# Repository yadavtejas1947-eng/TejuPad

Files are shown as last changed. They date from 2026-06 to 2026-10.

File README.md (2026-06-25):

# TejuPad
This is a 3*3 macropad built to increase your productivity by providing shortcut button for your most important tasks like pushing code , opening some app or website , controlling your music volume etc.  This Macropad is built on QMK firmware and matrix circuit using KiCad for the schematics and Fusion for the enclosure design.

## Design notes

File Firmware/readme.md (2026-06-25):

# teju_pad

`teju_pad` is a custom 3x3 QMK macropad powered by an RP2040 controller. It includes a rotary encoder, OLED display support, media keys, function keys, and per-key RGB matrix lighting using 9 WS2812/SK6812-style LEDs.

## Features

- 3x3 key matrix
- RP2040 MCU support
- Rotary encoder
- 128x64 OLED display over I2C
- RGB matrix lighting with 9 LEDs
- Media keys using QMK ExtraKey
- Bootmagic Lite support
- Dedicated RGB control layer
- Dedicated function-key layer

## Hardware

- **Keyboard Maintainer:** TejasYadav
- **MCU:** RP2040
- **Board:** `GENERIC_RP_RP2040`
- **Bootloader:** `rp2040`
- **Matrix:** 3 rows x 3 columns
- **Diode Direction:** `COL2ROW`
- **OLED:** 128x64 I2C display
- **RGB:** 9 WS2812/SK6812-style addressable LEDs

## Pinout

| Function | Pins |
| --- | --- |
| Rows | `GP3`, `GP0`, `GP7` |
| Columns | `GP27`, `GP6`, `GP29` |
| Encoder A/B | `GP2`, `GP1` |
| OLED SCL | `GP28` |
| OLED SDA | `GP4` |
| RGB Data | `GP26` |

## Default Layout

```text
Base layer
+---------+---------+---------+
|  Mute   | Vol -   | Vol +   |
+---------+---------+---------+
| KP 7    | KP 8    | KP 9    |
+---------+---------+---------+
| RGB     | KP 0    | FN      |
+---------+---------+---------+
```

```text
FN layer
+---------+---------+---------+
| F10     | F11     | F12     |
+---------+---------+---------+
| F7      | F8      | F9      |
+---------+---------+---------+
| F4      | F5      | Trans   |
+---------+---------+---------+
```

```text
RGB layer
+---------+---------+---------+
| Toggle  | Hue +   | Hue -   |
+---------+---------+---------+
| Sat +   | Sat -   | Val +   |
+---------+---------+---------+
| Trans   | Val -   | Boot    |
+---------+---------+---------+
```

## Encoder Behavior

| Active Layer | Counter-clockwise | Clockwise |
| --- | --- | --- |
| Base | Volume down | Volume up |
| FN | Page down | Page up |
| RGB | RGB brightness down | RGB brightness up |

## Building

From the QMK firmware root directory, build the default keymap with:

```sh
make teju_pad:default
```

## Flashing

Put the board into bootloader mode, then run:

```sh
make teju_pad:default:flash
```

## Bootloader

You can enter the bootloader in any of these ways:

- Hold the top-left key while plugging in the keyboard.
- Press the physical reset/boot button on the controller or PCB.
- Use the `QK_BOOT` key on the RGB layer.

## Disclaimer

This firmware was created with AI assistance:

- **Firmware:** Claude
- **README.md:** Codex

Please review, test, and verify the firmware on your own hardware before relying on it for daily use.

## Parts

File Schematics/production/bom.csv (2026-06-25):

Designator | Footprint | Quantity | Value | LCSC Part #
D1, D10, D2, D3, D4, D5, D6, D7, D8, D9 | D_DO-35_SOD27_P7.62mm_Horizontal | 10 | 1N4148
D11, D12, D13, D14, D15, D16, D17, D18, D19 | LED_SK6812MINI_PLCC4_3.5x3.5mm_P1.75mm | 9 | SK6812MINI
SW1, SW2, SW3, SW4, SW5, SW6, SW7, SW8, SW9 | SW_Cherry_MX_1.00u_PCB | 9 | SW_Push
SW10 | RotaryEncoder_Alps_EC11E-Switch_Vertical_H20mm | 1 | RotaryEncoder_Switch
U1 | ER_OLEDM0.91_1x-I2C | 1 | ER_OLEDM0.91_1x-I2C
U2 | XIAO-RP2040-DIP | 1 | XIAO-RP2040-DIP

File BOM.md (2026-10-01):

# TJ Pad — bill of materials

<!-- Generated by Half Life from project cmupau83t04sp01s1058a6cvx. Edits here are overwritten on the next sync. -->
<!-- Generated: 1970-01-01T00:00:00.000Z -->

> [!NOTE]
> This parts list is mirrored from [Half Life](https://halflife.hackclub.com). Editing it here will not change the platform's copy, and the next sync overwrites this file.

| Week | Tier | Parts funding |
| --- | --- | --- |
| Warm-up | Tier 1 | $30.00 |

_No parts listed yet._

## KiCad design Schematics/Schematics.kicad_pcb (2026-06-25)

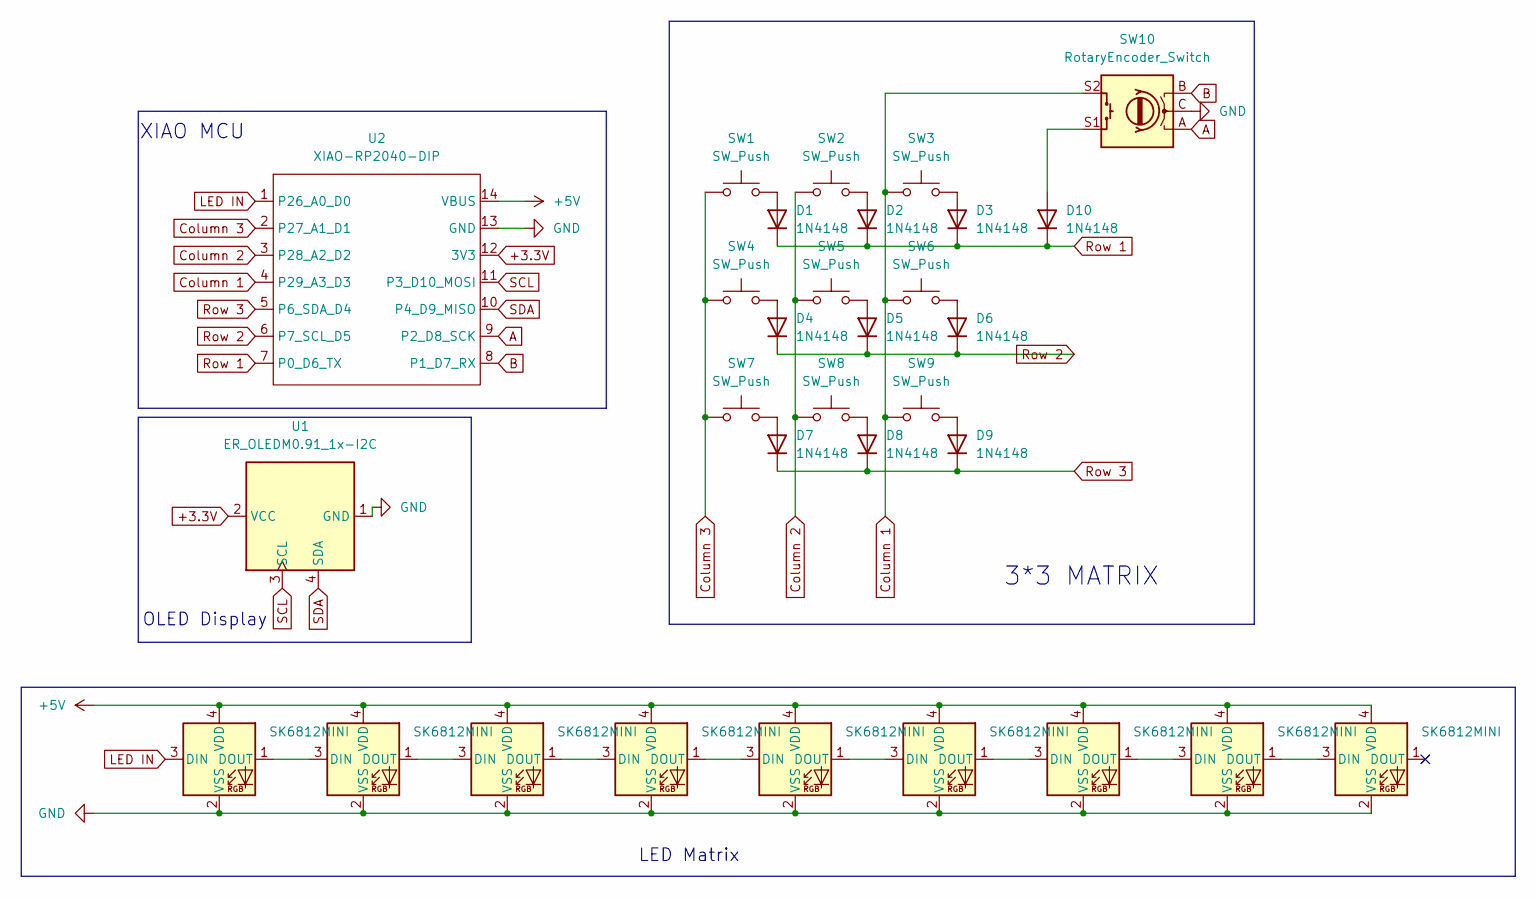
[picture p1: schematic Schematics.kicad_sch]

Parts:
D1, D2, D3, D4, D5, D6, D7, D8, D9, D10: 1N4148; D_DO-35_SOD27_P7.62mm_Horizontal
D11, D12, D13, D14, D15, D16, D17, D18, D19: SK6812MINI; LED_SK6812MINI_PLCC4_3.5x3.5mm_P1.75mm
SW1, SW2, SW3, SW4, SW5, SW6, SW7, SW8, SW9: SW_Push; SW_Cherry_MX_1.00u_PCB
SW10: RotaryEncoder_Switch; RotaryEncoder_Alps_EC11E-Switch_Vertical_H20mm
U1: ER_OLEDM0.91_1x-I2C
U2: XIAO-RP2040-DIP

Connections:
+3.3V: U1.2 (VCC), U2.12 (3V3)
+5V: D11.4 (VDD), D12.4 (VDD), D13.4 (VDD), D14.4 (VDD), D15.4 (VDD), D16.4 (VDD), D17.4 (VDD), D18.4 (VDD), D19.4 (VDD), U2.14 (VBUS)
A: SW10.A, U2.9 (P2_D8_SCK)
B: SW10.B, U2.8 (P1_D7_RX)
Column 1: SW3.1, SW6.1, SW9.1, SW10.S2, U2.4 (P29_A3_D3)
Column 2: SW2.1, SW5.1, SW8.1, U2.3 (P28_A2_D2)
Column 3: SW1.1, SW4.1, SW7.1, U2.2 (P27_A1_D1)
GND: D11.2 (VSS), D12.2 (VSS), D13.2 (VSS), D14.2 (VSS), D15.2 (VSS), D16.2 (VSS), D17.2 (VSS), D18.2 (VSS), D19.2 (VSS), SW10.C, U1.1 (GND), U2.13 (GND)
LED IN: D11.3 (DIN), U2.1 (P26_A0_D0)
unnamed: D1.2 (A), SW1.2
unnamed: D2.2 (A), SW2.2
unnamed: D3.2 (A), SW3.2
unnamed: D4.2 (A), SW4.2
unnamed: D5.2 (A), SW5.2
unnamed: D6.2 (A), SW6.2
unnamed: D7.2 (A), SW7.2
unnamed: D8.2 (A), SW8.2
unnamed: D9.2 (A), SW9.2
unnamed: D10.2 (A), SW10.S1
unnamed: D11.1 (DOUT), D12.3 (DIN)
unnamed: D12.1 (DOUT), D13.3 (DIN)
unnamed: D13.1 (DOUT), D14.3 (DIN)
unnamed: D14.1 (DOUT), D15.3 (DIN)
unnamed: D15.1 (DOUT), D16.3 (DIN)
unnamed: D16.1 (DOUT), D17.3 (DIN)
unnamed: D17.1 (DOUT), D18.3 (DIN)
unnamed: D18.1 (DOUT), D19.3 (DIN)
Row 1: D1.1 (K), D2.1 (K), D3.1 (K), D10.1 (K), U2.7 (P0_D6_TX)
Row 2: D4.1 (K), D5.1 (K), D6.1 (K), U2.6 (P7_SCL_D5)
Row 3: D7.1 (K), D8.1 (K), D9.1 (K), U2.5 (P6_SDA_D4)
SCL: U1.3 (SCL), U2.11 (P3_D10_MOSI)
SDA: U1.4 (SDA), U2.10 (P4_D9_MISO)

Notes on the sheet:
3*3 MATRIX
XIAO MCU
LED Matrix
OLED Display

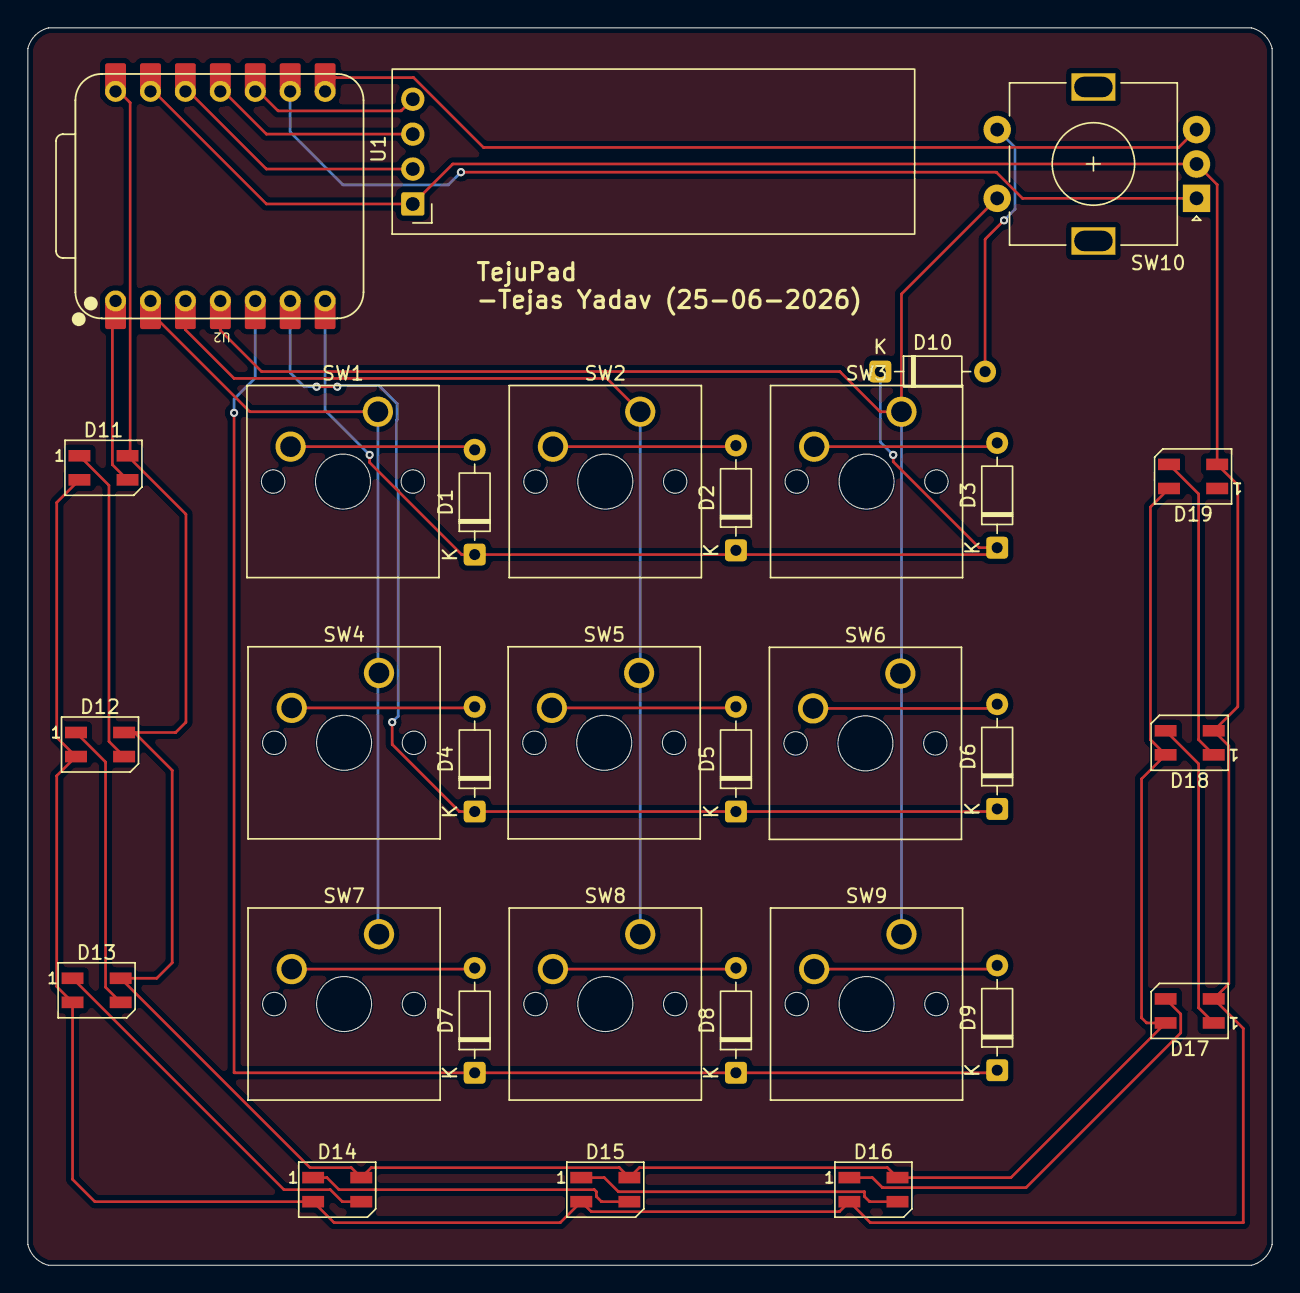
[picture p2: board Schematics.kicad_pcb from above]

Board: 2 copper layers, 90.5 x 90.0 mm, 31 parts (0 on the bottom side), 32 nets.

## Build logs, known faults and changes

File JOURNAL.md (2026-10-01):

# TJ Pad — devlog

<!-- Generated by Half Life from project cmupau83t04sp01s1058a6cvx. Edits here are overwritten on the next sync. -->
<!-- Generated: 1970-01-01T00:00:00.000Z -->

> [!NOTE]
> This devlog is mirrored from [Half Life](https://halflife.hackclub.com). Editing it here will not change the platform's copy, and the next sync overwrites this file.

> This is a 3*3 Macropad

| Week | Tier | Hours logged | Entries |
| --- | --- | --- | --- |
| Warm-up | Tier 1 | 0h | 0 |

_No entries logged yet._

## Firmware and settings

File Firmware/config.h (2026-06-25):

#pragma once

/* I2C for OLED — D2=GP28 (SCL), D9=GP4 (SDA) */
#define I2C_DRIVER        I2CD1
#define I2C1_SCL_PIN      GP28
#define I2C1_SDA_PIN      GP4

/* OLED */
#define OLED_DISPLAY_128X64
#define OLED_TIMEOUT      30000   /* turn off after 30s */

/* RGB Matrix — 9 SK6812MINI LEDs */
#define RGB_MATRIX_LED_COUNT 9
#define RGB_MATRIX_MAXIMUM_BRIGHTNESS 150
#define RGB_MATRIX_DEFAULT_MODE RGB_MATRIX_SOLID_COLOR
#define RGB_MATRIX_DEFAULT_HUE 0
#define RGB_MATRIX_DEFAULT_SAT 255
#define RGB_MATRIX_DEFAULT_VAL 80

/* Encoder */
#define ENCODER_RESOLUTION 4

/* Bootmagic key: top-left (0,0) */
#define BOOTMAGIC_LITE_ROW 0
#define BOOTMAGIC_LITE_COLUMN 0

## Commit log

2026-06-25 PCB and Schematics
    [Schematics.kicad_pcb, Schematics.kicad_sch, bom.csv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]
2026-10-27 Document progress of TejuPad development in JOURNAL.md
    Added entries for days 1 to 4 of the TejuPad development, detailing progress on schematics, PCB design, and firmware coding.
